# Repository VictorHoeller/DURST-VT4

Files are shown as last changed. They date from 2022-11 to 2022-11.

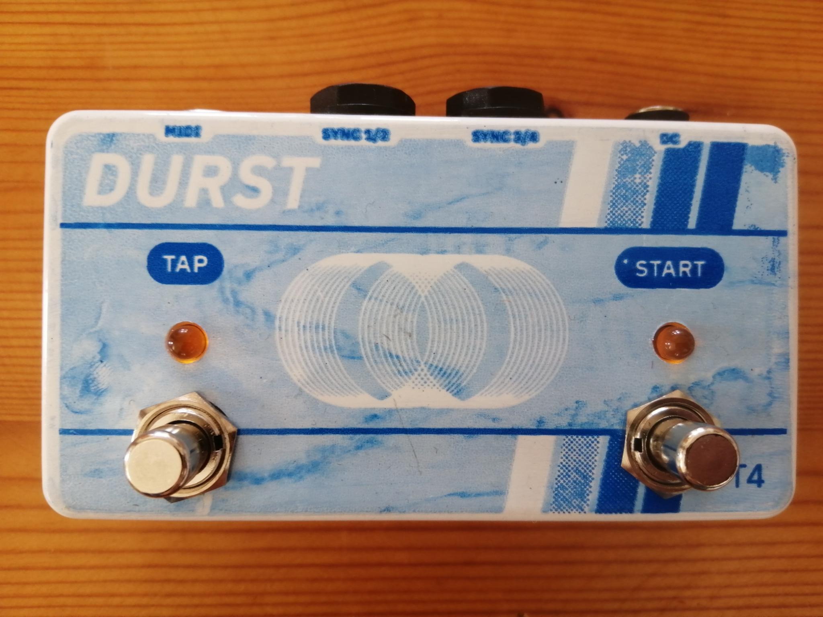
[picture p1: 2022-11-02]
signal-2022-10-12-124551_004.jpeg

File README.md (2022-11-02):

# DURST-VT4
It is a tap tempo pedal with which you can synchronize and start external MIDI devices, such as beat machines and other sequencers. Furthermore, external effect pedals with tap input can also be synchronized to the same speed. Mostly these are delay (DOD Rubberneck) or modulation pedals.
The pedal acts as a MIDI master clock.

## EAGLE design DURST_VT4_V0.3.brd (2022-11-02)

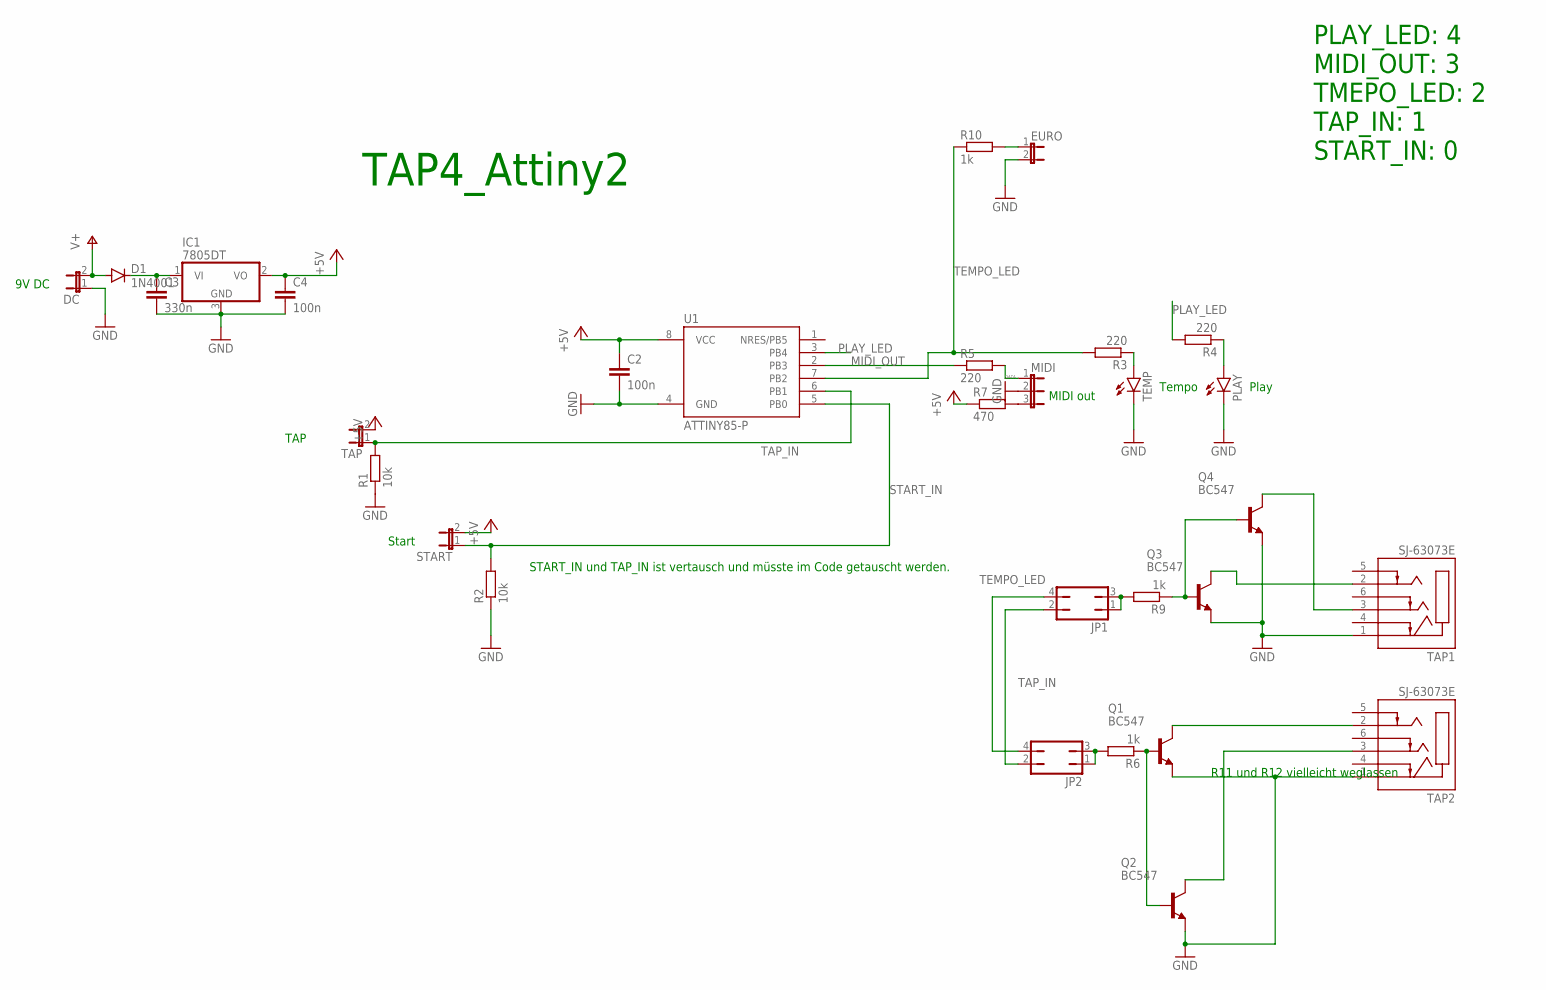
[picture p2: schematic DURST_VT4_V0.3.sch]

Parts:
C2: 100n; C050-024X044
C3: 330n; C025-024X044
C4: 100n; C025-024X044
D1: 1N4001; DO41-10
DC: JP1E; JP1
EURO: JP1E; JP1
IC1: 7805DT; TO252
JP1, JP2: JP2Q
MIDI: JP2E; JP2
PLAY: LED5MM
Q1, Q2, Q3, Q4: BC547; TO92
R1, R2: 10k; 0309/10
R3, R4, R5: 220; 0309/10
R6, R9, R10: 1k; 0309/10
R7: 470; 0309/10
START: JP1E; JP1
TAP: JP1E; JP1
TAP1, TAP2: SJ-63073E; CUI_SJ-63073E
TEMP: LED5MM
U1: ATTINY85-P; PDIP08_300MIL

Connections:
+5V: C2.1, C4.1, IC1.2 (VO), R7.1, START.2, TAP.2, U1.8 (VCC)
DATA: MIDI.1, R5.2
GND: C2.2, C3.2, C4.2, DC.1, EURO.2, IC1.3 (GND), MIDI.2, PLAY.K (C), Q1.1 (E), Q2.1 (E), Q3.1 (E), Q4.1 (E), R1.1, R2.1, TAP1.1 (SLEEVE), TAP2.1 (SLEEVE), TEMP.K (C), U1.4 (GND)
MIDI_OUT: R5.1, U1.2 (PB3)
unnamed: EURO.1, R10.2
unnamed: Q4.3 (C), TAP1.3 (RING)
unnamed: Q2.3 (C), TAP2.3 (RING)
unnamed: R3.1, TEMP.A
unnamed: PLAY.A, R4.1
unnamed: JP1.1, JP1.3, R9.2
unnamed: C3.1, D1.C, IC1.1 (VI)
unnamed: JP2.1, JP2.3, R6.2
unnamed: MIDI.3, R7.2
unnamed: Q3.3 (C), TAP1.2 (TIP)
unnamed: Q1.3 (C), TAP2.2 (TIP)
unnamed: Q1.2 (B), Q2.2 (B), R6.1
unnamed: Q3.2 (B), Q4.2 (B), R9.1
PLAY_LED: R4.2, U1.3 (PB4)
START_IN: R2.2, START.1, U1.5 (PB0)
TAP_IN: JP1.2, JP2.2, R1.2, TAP.1, U1.6 (PB1)
TEMPO_LED: JP1.4, JP2.4, R3.2, R10.1, U1.7 (PB2)
V+: D1.A, DC.2

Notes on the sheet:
9V DC
TAP
Start
Tempo
Play
MIDI out
TAP4_Attiny2
R11 und R12 vielleicht weglassen
START_IN und TAP_IN ist vertausch und müsste im Code getauscht werden.
PLAY_LED: 4 MIDI_OUT: 3 TMEPO_LED: 2 TAP_IN: 1 START_IN: 0

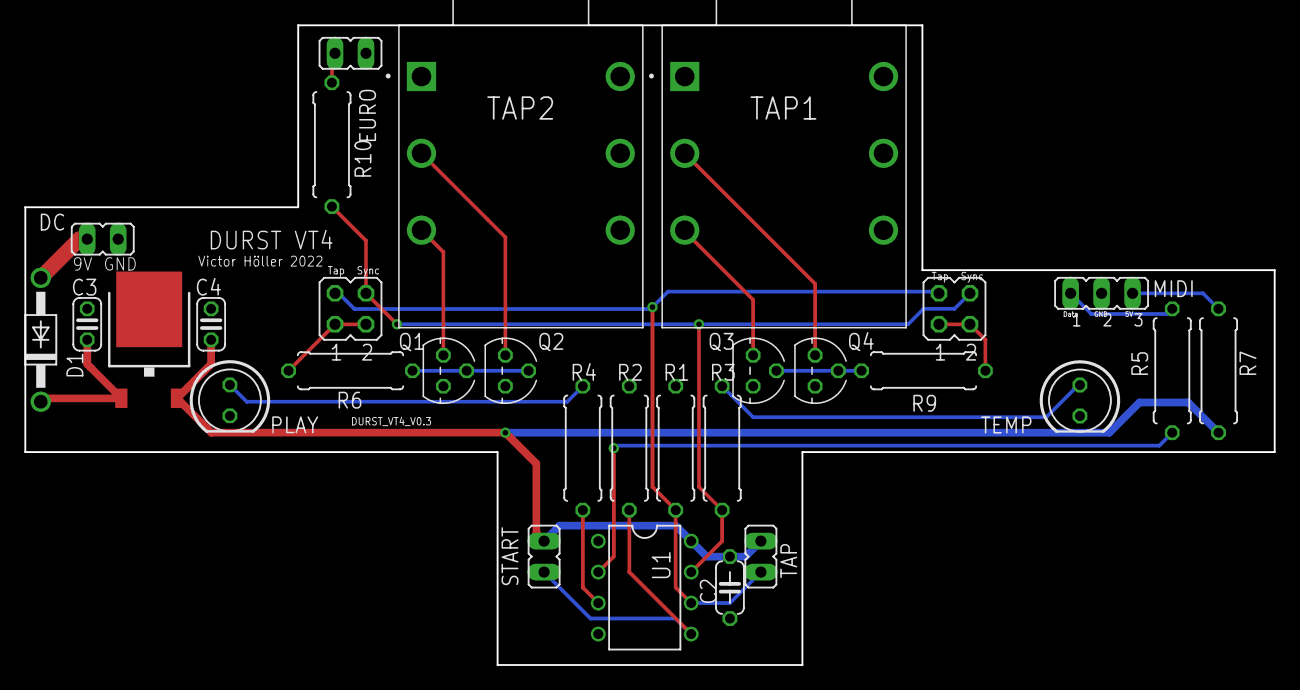
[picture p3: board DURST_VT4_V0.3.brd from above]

Board: 2 copper layers, 102.5 x 52.5 mm, 30 parts (0 on the bottom side), 22 nets.

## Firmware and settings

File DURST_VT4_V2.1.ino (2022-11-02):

// written by Victor Höller 2022
// V2.1
// fits for Board: DURST_VT4_V0.3
// use TimerOne.h from this side: https://github.com/PaulStoffregen/TimerOne
// replace the TimerOne folder C:\Users\Victor Höller\Documents\Arduino\libraries

//NEU: Zeile 66, 104

#include <TimerOne.h>
#include <EEPROM.h>
#include <Bounce2.h>
#include <SendOnlySoftwareSerial.h>
SendOnlySoftwareSerial midiSerial(3);

#define START_IN 0
#define TAP_IN 1
#define TEMPO_LED 2
#define PLAY_LED 4

#define BLINK_TIME 5

#define MIDI_START 0xFA
#define MIDI_STOP 0xFC

#define MIDI_TIMING_CLOCK 0xF8
#define CLOCKS_PER_BEAT 24

// BPM Variablen
Bounce A = Bounce();
Bounce B = Bounce();
float bpm = EEPROM.read(0);
float bpm_dec = EEPROM.read(1);
byte anzahl_press = 0;
long last_tap;
long now;
bool saved = true;

float bpm4;
float bpm3;
float bpm2;
float bpm1;
float bpm0;

// Algemeine Variablen
volatile int blinkCount = 0;

// Midi Variablen
long intervalMicroSeconds;
boolean playing = false;

void setup() {
  midiSerial.begin(31250);
  pinMode(TEMPO_LED, OUTPUT);
  pinMode(PLAY_LED, OUTPUT);

  // Attach the interrupt to send the MIDI clock and start the timer
  Timer1.initialize(intervalMicroSeconds);
  Timer1.setPeriod(calculateIntervalMicroSecs(bpm));
  Timer1.attachInterrupt(sendClockPulse);

  A.attach(TAP_IN, INPUT);
  A.interval(25);
  B.attach(START_IN, INPUT);
  B.interval(25);

  // bpm = bpm + bpm_dec/100;
}

void loop() {
  // Prozedur, wenn Tap gedrückt und debouncen des Tasters
  A.update();
  now = millis();  // Aktuelle Zeit in Millisekunden
  if (A.rose()) {
    anzahl_press++;               // erhöht den Wert der Tasthäufigkeit um 1
    if (anzahl_press > 1) {
      bpm4 = 60000 / float(now - last_tap);
      if (anzahl_press == 2) {
        bpm0 = bpm4;
        bpm1 = bpm4;
        bpm2 = bpm4;
        bpm3 = bpm4;
      }
      else {
        bpm0 = bpm1;
        bpm1 = bpm2;
        bpm2 = bpm3;
        bpm3 = bpm4;
      }
      bpm = (bpm4 + bpm3 + bpm2 + bpm1 + bpm0) / 5;
      Timer1.setPeriod(calculateIntervalMicroSecs(bpm));
      saved = false;
    }
    last_tap = now;
  }

  // Schaut, ob eine NEUE Sequenz begonnen werden soll
  if (now - last_tap > 2000) {  // nach 2 Sekunden gehört ein Tap nicht mehr zu der alten Sequenz und eine neue wird begonnen
    anzahl_press = 0;           // Anzahl Pressungen wird auf Null gesetzt.
    if (saved == false) {
      if (bpm > 255) {
        bpm = 255;
      }
      EEPROM.write(0, byte(bpm));
      //EEPROM.write(1, byte((bpm - byte(bpm) * 100)));
      saved = true;
    }
  }

  B.update();
  // Schaut, ob Startknopf gedrückt wurde
  if (B.fell()) {
    startOrStop();
  }
}

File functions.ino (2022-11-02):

// Funktionen:

// Tap Tempo
void sendClockPulse() {
  midiSerial.write(MIDI_TIMING_CLOCK);
  LEDblink();
}

long calculateIntervalMicroSecs(float bpm) {
  // Take care about overflows!
  return 60L * 1000000 / bpm / CLOCKS_PER_BEAT / 0.9795; //0.9864268;  // Attiny correction
}

// Start Stopp
void startOrStop() {
  if (!playing) {
    midiSerial.write(MIDI_START);
    digitalWrite(PLAY_LED, HIGH);
  } else {
    midiSerial.write(MIDI_STOP);
    digitalWrite(PLAY_LED, LOW);
  }
  playing = !playing;
}

// LED
void LEDblink() {
  blinkCount = (blinkCount + 1) % CLOCKS_PER_BEAT;
  if (blinkCount == 0) {
    digitalWrite(TEMPO_LED, HIGH);
  }
  else {
    if (blinkCount == BLINK_TIME) {
      digitalWrite(TEMPO_LED, LOW);
    }
  }
}
